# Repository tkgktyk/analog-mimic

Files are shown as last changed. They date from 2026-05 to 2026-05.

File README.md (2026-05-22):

# Analog Mimic (analog-mimic)

<!-- ![Analog Mimic Board](docs/images/analog_mimic_board.jpg) -->

## Overview
Analog Mimic is a drop-in, programmable analog front-end (AFE) module powered by a robust "MCU + DSP" architecture. It is designed to bring software-defined flexibility to physical analog boundaries.

**Key Features:**
* **Versatile Emulation:** Physically mimics diverse analog circuits (e.g., filters, amplifiers, comparators).
* **Instant Reconfiguration:** Fully reconfigurable on the fly with a single I²C command.
* **Drop-in Ready:** Designed to be easily integrated into your existing hardware prototyping workflow.

<!-- ## Underlying Technology
**Analog Mimic is powered by OtoHA.**

OtoHA (Optimization toward Hardware-deterministic Architecture) is the foundational framework established in our IEEE ESL paper: *"Sub-Clock Hardware-Deterministic Architecture for Phase-Accurate Analog Emulation on Resource-Constrained MCUs"*. 

By isolating the critical execution path and eliminating architectural timing penalties, OtoHA ensures strict time-invariance and hardware-like precision, allowing standard microcontrollers to operate as strictly deterministic mixed-signal blocks. -->

## Hardware Concept
* **Form Factor:** Pmod Type 6 (I²C) compatible layout with a compact, breadboard-friendly footprint (35.56 mm × 20 mm).
* **On-Chip Integration:** Seamless integration of internal operational amplifier-based input/output buffers, anti-aliasing filters (AAF), and anti-imaging filters (AIF) mapped directly alongside the high-speed processing core.

## Software Ecosystem
To lower the barrier to entry for real-time digital signal processing, we provide a dedicated **C++ library for Arduino**. 
* **Zero-Hassle Control:** Complex Q15 fixed-point arithmetic and low-level I²C register maps are completely abstracted away.
* **Intuitive High-Level API:** Users can dynamically switch emulation modes and fine-tune physical parameters—such as cutoff frequencies, amplifier gains, or envelope release times—by simply passing variables into straightforward function calls.

*For comprehensive details on the inner workings, execution framework, and API configurations, please refer to [firmware_reference.md](docs/firmware_reference.md) and the Doxygen-annotated [Mimic.h](software/Mimic/src/Mimic.h).*

## Product Lineup
* **mimic0x (Standard Type):** The base model optimized for standard analog emulation and generalized mixed-signal prototyping.
* **mimic1x (AFE Extended Type):** An enhanced version featuring expanded hardware-level analog front-end scaling for specialized sensor interfacing.

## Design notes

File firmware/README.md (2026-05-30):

# firmware/README.md

This directory contains the core firmware source code, peripheral drivers, and build configurations for the Analog Mimic module. This guide outlines the setup required for compiling the firmware from source and flashing the compiled binary onto the target microcontroller.

## 1. Development Environment Setup

Analog Mimic firmware is targeted for the Puya Semiconductor PY32F071 MCU (Arm Cortex-M0+, 72 MHz). To compile and flash the firmware, the following toolchains and utility tools are required.

### Required Software Components

1. **GCC ARM Embedded Toolchain (`arm-none-eabi-gcc`)**
* Used for compiling and linking the C/C++ source code into an ARM architecture binary.
* Ensure it is added to your system environment variable `PATH`.

2. **Build Automation Tool (`make` or `CMake`)**
* Standard GNU Make is utilized to execute the compilation pipeline via the `Makefile`.

3. **Python 3.x & pyOCD**
* pyOCD is an open-source Python library used for programming and debugging ARM Cortex microcontrollers via a CMSIS-DAP debugger.

---

## 2. Compilation and Build Pipeline

To compile the firmware, navigate to this directory and use the build configuration. The optimization flags are strictly configured (`-O2` or `-O3`) to meet the strict 240-clock-cycle budget for the 300 kHz primary ISR loop, and `.ramfunc` routes time-critical instructions into zero-wait-state SRAM.

### Build Commands

* **Compile Firmware:**
```bash
make release
```

*This generates the compiler outputs in the `build/` directory, resulting in `analog_mimic_MIMIC00.elf`, `.bin`, and `.hex` files.*
* **Clean Build Artifacts:**
```bash
make clean
```

---

## 3. Flashing & Debug Environment

Target programming is handled asynchronously via the SWD (Serial Wire Debug) pins using a standard CMSIS-DAP compliant debug probe.

### Target MCU Specification

* **Target Device:** Puya PY32F071xB
* **Memory Config:** 128 KB Flash / 16 KB SRAM

### Flash Programming via pyOCD

pyOCD natively supports the PY32 series by loading the corresponding device pack. Execute the following continuous command to flash the compiled production Intel HEX image onto the MCU:

```bash
pyocd flash -t py32f071xb analog_mimic_MIMIC00.hex

```

### Hardware Verification Setup

```
[ Host PC ]
    │ (USB)
    ▼
[ CMSIS-DAP Debugger ] (e.g., DAPLink, J-Link in DAP mode)
    │ (SWD Interface: SWCLK, SWDIO, GND, 3.3V)
    ▼
[ Analog Mimic Board ] (PY32F071 Target Pins)

```

1. Connect your CMSIS-DAP debugger to the SWD test points on the Analog Mimic PCB.
2. Power the module via the Pmod interface or the VDD pin (3.3V).
3. Run the `pyocd flash` command. Upon successful completion, reset the MCU to initiate the execution framework and launch the 300 kHz ADC sampling pipeline.

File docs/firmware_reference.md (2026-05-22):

# Firmware Reference

This document provides a technical overview of the Analog Mimic firmware. It details the OtoHA execution framework, hardware resource allocations, internal DSP mechanics, and the I²C control interface, serving as a guide for users who wish to understand the core software pipeline.

## 1. Internal MCU Processing

The firmware pipeline executes sequentially within the hardware-locked Primary ISR to maintain absolute temporal determinism.

```
[Analog In]
   ↓
(1) ADC Read (12-bit Raw)
   ↓
(2) Mode-Specific DSP Core (32-bit state execution)
   ↓
(3) Common Post-processing 1: Branchless DAC Code Inversion & DC Offset
   ↓
(4) Common Post-processing 2: Fixed-point Saturation (Clamps strictly to 0 - 4095)
   ↓
(5) DAC Preload (Next cycle output)
   ↓
[Analog Out]

```

---

## 2. Hardware Resource Mapping

Analog Mimic is built around the Puya Semiconductor PY32F071, a low-cost 72 MHz Arm Cortex-M0+ MCU. The continuous-time signal chain defined in the architecture is mapped directly to the MCU's internal peripherals.

### Peripheral Assignment Table

| Hardware Resource | Internal Peripheral | Firmware Function / Mapping |
| --- | --- | --- |
| **System Core Clock** | HSI Oscillator | Configured to 72 MHz via internal PLL. |
| **Sampling Clock** | TIM3 (16-bit Advanced Timer) | Configured in up-counting mode to generate periodic Update Interrupts at exactly 300 kHz (Priority 0: Primary ISR). |
| **Input Buffer** | OPA1 | Configured as a Hi-Z voltage follower. |
| **Anti-Aliasing Filter (AAF)** | OPA3 | Configured as a 2nd-order Sallen-Key Low-Pass Filter ($Q = 0.5$, $f_c = 48.2$ kHz). |
| **Analog Input Interface** | ADC1 (12-bit, Successive Approx.) | Mapped to internal channels or pins depending on the variant. Set to high-speed single-conversion mode triggered automatically by the timer. |
| **Primary Analog Output** | DAC1 (12-bit R-2R Ladder) | Wired directly to the output smoothing chain (AOUT). Driven by an immediate software trigger (SWTRIGR = 1) at the very first instruction of the Primary ISR, latching the pre-calculated code. |
| **Anti-Imaging Filter (AIF)** | OPA2 | Configured as a 2nd-order Sallen-Key Low-Pass Filter ($Q = 0.5$, $f_c = 48.2$ kHz). |
| **Host Communication** | I2C1 (Hardware Block) | Mapped to Scl/Sda lines for host-level runtime reconfiguration (Priority 1: Secondary ISR). |

---

<!-- ## 3. OtoHA Execution Framework

Analog Mimic achieves hardware-like temporal determinism on a resource-constrained microcontroller by implementing the OtoHA (Optimization toward Hardware-deterministic Architecture) framework. To balance strict phase-accuracy with topological reconfigurability, the firmware bifurcates execution into two distinct states.

### Hardware and Software Mapping

```
+---------------------------------------------------------------------------------+
|                                 MCU EXECUTION                                   |
+---------------------------------------------------------------------------------+
|  [Deterministic State]                         [Non-Deterministic State]        |
|                                                                                 |
|  Primary ISR                                   Secondary ISR      Main Loop     |
|  (Priority 0)                                  (Priority 1)       (Background)  |
|       │                                             │                  │        |
|       ▼                                             ▼                  ▼        |
|  Tied directly to:                             Tied to:           Tied to:      |
|  300 kHz Hardware Timer                        Asynchronous       Parameter     |
|  & Periodic ADC Sampling                       I2C Transactions   Decoding &    |
|                                                                   Q15 Scaling   |
+---------------------------------------------------------------------------------+

```

### Deterministic State (Mapped to Primary ISR & 300 kHz ADC Sampling)

* **Hardware Binding:** This state is implemented inside the Primary ISR, which is tied directly to a hardware timer interrupt set to a strict 300 kHz sampling rate (3.3 µs sample period). This timer commands the ADC to initiate conversions at absolute periodic intervals.
* **Execution Pipeline:** Executes the time-critical mixed-signal chain. Upon the 300 kHz hardware trigger, the CPU bypasses standard interrupt latencies to issue an immediate software trigger to the DAC (presenting the pre-calculated analog code from the previous sample). It then reads the newly converted 12-bit raw value from the ADC, routes it through the active 32-bit promoted DSP emulation core, and performs common post-processing (branchless inversion, offset, and clamping) to preload the DAC for the next cycle.
* **Zero-Jitter Optimizations:** To guarantee sub-clock execution determinism (<13 ns jitter) across the 300 kHz ADC boundary, the NVIC vector table and the entire Primary ISR instruction routine are moved to zero-wait-state SRAM via the `.ramfunc` attribute. Active emulation explicitly suspends asynchronous system background tasks (such as the standard SysTick handler) to prevent nested preemption.

### Non-Deterministic State (Mapped to I²C Interrupts & Main Loop)

* **Hardware Binding:** This state handles external host communication and is bifurcated into the I²C peripheral interrupt (Secondary ISR) and the background Main Loop.
* **Execution Pipeline:** Manages topological and parameter updates. When a host microcontroller (e.g., an Arduino) issues a configuration command, the hardware I²C interrupt (Secondary ISR) triggers at a lower priority (Priority 1) to capture incoming payload bytes into a temporary data buffer without interrupting the active Primary ISR. Once the transfer completes, the background Main Loop takes over to decode the commands, translate human-readable physical parameters (such as cutoff frequencies in Hz or decay times in microseconds) into digital raw values or Q15 fixed-point coefficients, and safely hot-swaps the DSP routing mode.

### Cycle Budget Allocation

Operating a 72 MHz Cortex-M0+ core at a 300 kHz sampling rate compresses the total single-sample computational window into a strict budget of 240 clock cycles per sample.

```
5 µs Sample Period @ 72 MHz Core Clock
|←───────────────────────── 240 Clock Cycles ─────────────────────────→|
┌───────────────────────────────────────────────┬──────────────────────┐
│ Core DSP Execution                            │ Required Slack       │
│ (e.g., Fixed-Point Emulation Routine)         │ (60 - 70 Cycles)     │
└───────────────────────────────────────────────┴──────────────────────┘
                                                ▲
                                                └── Mapped to:
                                                    - I2C ISR Overhead
                                                    - Main Loop Decoding

```

* **DSP Execution:** Highly optimized fixed-point routines execute inside the Primary ISR, consuming a predictable chunk of the sample budget.
* **Slack Margin:** The framework rigorously maintains a required slack margin of 60 to 70 clock cycles outside of the core DSP execution. This deterministic cycle reserve is dedicated entirely to non-DSP operations—specifically handling the I²C Secondary ISR communication overhead and allowing the background Main Loop to calculate new filter coefficients before the next WFI (Wait-For-Interrupt) synchronization boundary.

--- -->

## 4. DSP Core & Fixed-Point Arithmetic

To maximize efficiency within the 240-cycle budget, the firmware completely avoids runtime floating-point arithmetic. All mathematical emulation blocks are implemented using a 32-bit promoted Q15 fixed-point representation.

### Fixed-Point Format & 32-bit Promotion

In the Q15 format, a signed integer represents a fractional value in the range $[-1.0, 1.0 - 2^{-15}]$:

$$\text{Value}_{\text{Float}} = \frac{\text{Internal integer}}{32768}$$

To eliminate memory alignment padding gaps and avoid redundant CPU cast instructions on the 32-bit Cortex-M0+ architecture, all internal DSP states and arithmetic operations are natively promoted to `int32_t` (`FRACTIONAL_BITS_Q15 = 15`).

* **Addition / Subtraction:** Executed natively using 32-bit registers.
* **Multiplication:** Performed using native 32-bit arithmetic. The 32-bit intermediate product is immediately shifted right by 15 bits (`>> 15`) to maintain the Q15 fractional scale, without dropping back to 16 bits until the final DAC bounds clamping.

### Parameter Processing & Scaling

When a host passes a physical parameter (such as a cutoff frequency in Hz or an integration time constant in microseconds) over I²C, the firmware does not use these values directly inside the Primary ISR. Instead, the Secondary ISR intercepts the parameters and converts them into normalized digital coefficients (such as $b_0, b_1, a_1$ coefficients or pre-calculated decay multipliers) using a background fixed-point conversion library.

* **Voltage Inputs (mV to Raw 12-bit ADC/DAC Codes):**
* Unsigned:

$$\text{Raw} = \frac{\text{mV} \times 4095}{V_{DD\_mV}}$$

* Signed (Centered around $V_{DD}/2$ mid-rail):

$$\text{Raw}_{\text{Signed}} = \frac{\text{mV} \times 2048}{V_{DD\_mV}/2}$$

* **Frequency Inputs ($f_c$ in Hz to Biquad Coeffs):**
Pre-warped digital angular frequencies $\omega_0 = 2\pi f_c / f_s$ are mapped to Q15 filter coefficients using optimized Taylor-series polynomial approximations for sine and cosine.

### Parameter Specification & Payload Types Table

When the host configures a DSP mode, it sends parameters over I²C using specific data types. The following table defines these payload types, classifying how human-readable physical units are translated into the raw bytes utilized by the DSP core.

| Payload Type | Logical Parameter | User/Host Unit | Hardware / Internal Mapping |
| --- | --- | --- | --- |
| **S16** *(Signed 16-bit)* | Q15 Coefficient (Freq $f_c$, Time Const $\tau$, Gain) | Hz, $\mu$s, or Float | Converted by the host into Q15 fractional format $[-1.0, 1.0)$. Used internally for digital filters ($b_n, a_n$), integration/decay factors, and fractional scaling. |
| **S16 / U16** *(16-bit Integer)* | Raw ADC Code / Offset (Threshold, $V_{\text{ref}}$, DC Offset) | mV | Transformed by the host from physical voltage to a 12-bit raw integer $[0 - 4095]$. U16 is typically used for absolute thresholds, while S16 is used for offsets and clipping limits. |
| **S8** *(Signed 8-bit)* | Bit-Shift Multiplier (Coarse Gain) | Integer | Used in conjunction with Q15 fractional multipliers. Performs fast coarse scaling via bit-shifting (e.g., $\ll 2$ for $4\times$ gain, or $\gg 1$ for attenuation). |
| **U16** *(Unsigned 16-bit)* | Sample Count (Delay time, S&H period) | Samples (Integer) | Represents an exact number of 300 kHz clock cycles. Used directly for delay buffer sizing and downsampling counters. |
| **U8** *(Unsigned 8-bit)* | Flag / Enumeration (Polarity, LUT Type) | Boolean / Enum | Simple 1-byte selection codes. Maps to conditional branching flags (e.g., peak vs. trough) or Look-Up Table target pointers. |

---

## 5. I²C Interface & Mode Specifications

The internal topology of the Analog Mimic is fully reconfigurable at runtime via an 8-bit memory-mapped I²C register interface.

### Register Map Overview

The device utilizes a fixed memory map bridging host interactions and the internal DSP state machine. Registers 0x00 through 0x1F reside in physical SRAM (`mimic_device.registers`), whereas telemetry addresses (0x20+) are virtual and dynamically latched upon host read requests to guarantee thread safety.

| Address | Register Name | Access | Width | Description |
| --- | --- | --- | --- | --- |
| **0x00** | MIMIC_REG_GLOBAL_FLAGS | R/W | 8-bit | System overrides. Bit 7 (0x80): Output Invert, Bit 6 (0x40): Output Open (Hi-Z), Bit 5 (0x20): Servo Enable. |
| **0x01** | MIMIC_REG_OUTPUT_OFFSET_H | R/W | 8-bit | MSB of global DC offset applied universally post-DSP. |
| **0x02** | MIMIC_REG_OUTPUT_OFFSET_L | R/W | 8-bit | LSB of global DC offset. |
| **0x10** | MIMIC_REG_MODE_SELECT | R/W | 8-bit | Selects the active DSP routing topology (Mode ID). |
| **0x11+** | MIMIC_REG_PAYLOAD_START | R/W | Block | Mode-specific parameter buffer. Interpreted based on MODE_SELECT. |
| **0x20** | MIMIC_REG_STATUS | R/C | 8-bit | System Status Flags (Bit 0: Ready, Bit 1: Saturation, Bit 2: I2C Error, Bit 3: ADC Over Error). Cleared on read. |
| **0x21** | MIMIC_REG_ADC_VAL_H | R | 8-bit | MSB of the live 12-bit ADC tracking conversion. |
| **0x22** | MIMIC_REG_ADC_VAL_L | R | 8-bit | LSB of the live 12-bit ADC conversion. |
| **0x23** | MIMIC_REG_CPU_CYCLES_H | R/C | 8-bit | MSB of peak execution cycles per sample. Cleared on read. |
| **0x24** | MIMIC_REG_CPU_CYCLES_L | R/C | 8-bit | LSB of peak execution cycles per sample. |

### Operational Mode Specifications

The host triggers a pipeline reconfiguration by writing the target Mode ID to `MIMIC_REG_MODE_SELECT` (0x10), followed by mode-specific bytes starting at `MIMIC_REG_PAYLOAD_START` (0x11).

#### 0x00: DSP Bypass (`MIMIC_MODE_ID_BYPASS_DSP`)

* **Function:** Acts as a strictly deterministic voltage follower.
* **Implementation:** The ADC input is routed directly to the DAC. Global pipeline effects (Inversion, Offset) remain active.
* **Payload Parameters:** None.

#### 0x01: Programmable Gain Amplifier (`MIMIC_MODE_ID_PGA`)

* **Function:** Scales the input signal linearly with respect to an arbitrary reference center.
* **Implementation:** Combines a Q15 fractional multiplier for fine-tuning and a bit-shift operation for gross hardware-like amplification.
* **Payload Parameters:** * 0x11-0x12 (S16): `gain_fract_q15` - Fractional gain multiplier.
* 0x13 (S8): `gain_shift` - Coarse bit-shift multiplier.
* 0x14-0x15 (S16): `offset_raw` - DC offset reference center (Raw ADC code). Internally mapped to Q15.

#### 0x02: 1st-Order Low-Pass Filter (`MIMIC_MODE_ID_FILTER_1ST_LPF`)

* **Function:** Emulates a continuous-time RC low-pass filter.
* **Implementation:** Standard infinite impulse response (IIR) single-pole accumulator.
* **Payload Parameters:**
* 0x11-0x12 (S16): `alpha_q15` - Decay/Integration coefficient derived from target $f_c$.

#### 0x03: 1st-Order High-Pass Filter (`MIMIC_MODE_ID_FILTER_1ST_HPF`)

* **Function:** Emulates an RC high-pass network (useful for automatic DC-blocking/servo tracking).
* **Implementation:** Single-pole accumulator with the state subtracted from the raw input.
* **Payload Parameters:**
* 0x11-0x12 (S16): `alpha_q15` - Cutoff frequency coefficient.

#### 0x04: 2nd-Order Biquad Filter (`MIMIC_MODE_ID_FILTER_BIQUAD`)

* **Function:** Universal 2nd-order digital filter configurable as LPF, HPF, BPF, or Notch.
* **Implementation:** Direct Form II Transposed (DF2T). Highly unrolled loop loading coefficients aggressively into CPU registers. Dominates the processing budget (~212 cycles).
* **Payload Parameters:**
* 0x11-0x12 (S16): `b0` - Feedforward coefficient 0.
* 0x13-0x14 (S16): `b1` - Feedforward coefficient 1.
* 0x15-0x16 (S16): `b2` - Feedforward coefficient 2.
* 0x17-0x18 (S16): `a1` - Feedback coefficient 1.
* 0x19-0x1A (S16): `a2` - Feedback coefficient 2.

#### 0x05: Window Comparator (`MIMIC_MODE_ID_COMPARATOR_WIN`)

* **Function:** Triggers output HIGH when the signal escapes the defined upper/lower boundaries.
* **Implementation:** Pure conditional branching logic outputting absolute 12-bit limits.
* **Payload Parameters:**
* 0x11-0x12 (U16): `upper` - Raw ADC threshold code (Upper bound).
* 0x13-0x14 (U16): `lower` - Raw ADC threshold code (Lower bound).

#### 0x06: Schmitt Trigger (`MIMIC_MODE_ID_COMPARATOR_SCHMITT`)

* **Function:** A comparator with hysteresis memory, preventing noisy transitions.
* **Implementation:** Conditional branching retaining state memory (`wave_last_raw`).
* **Payload Parameters:**
* 0x11-0x12 (U16): `upper` - Trigger HIGH threshold.
* 0x13-0x14 (U16): `lower` - Trigger LOW threshold.

#### 0x07: Envelope Follower (`MIMIC_MODE_ID_ENVELOPE_FOLLOWER`)

* **Function:** Tracks amplitude peaks (or troughs) with a customizable decay release time. Acts as a Peak Hold if decay is zero.
* **Implementation:** Multiplies the historical state by a Q15 decay factor when the input falls below the tracked envelope.
* **Payload Parameters:**
* 0x11-0x12 (S16): `decay_q15` - Q15 decay factor (derived from $\tau$ us).
* 0x13 (U8): `polarity` - Positive peak (0) or Negative trough (1) tracking.

#### 0x08: Signal Clipper (`MIMIC_MODE_ID_CLIPPER`)

* **Function:** Clamps the output signal strictly within absolute physical voltage boundaries.
* **Implementation:** Standard boundary threshold branching limits.
* **Payload Parameters:**
* 0x11-0x12 (S16): `upper` - Upper clamp limit (Raw).
* 0x13-0x14 (S16): `lower` - Lower clamp limit (Raw).

#### 0x09: Non-linear LUT Waveshaper (`MIMIC_MODE_ID_NONLINEAR_LUT`)

* **Function:** Emulates analog logarithmic and anti-logarithmic amplification curves.
* **Implementation:** Instead of heavy runtime Taylor series execution, maps a pre-computed 65-point Look-Up Table (LUT) across the ADC range, utilizing single-cycle linear interpolation for sub-index accuracy.
* **Payload Parameters:**
* 0x11 (U8): `lut_type` - 0 for Logarithmic, 1 for Anti-Logarithmic.

#### 0x0A: Signal Derivative (`MIMIC_MODE_ID_MATH_DERIVATIVE`)

* **Function:** Mathematical differentiator (extracts the rate of change).
* **Implementation:** Calculates $\Delta$ between the current and previous sample, scaled by a fractional Q15 multiplier and bit-shift.
* **Payload Parameters:**
* 0x11-0x12 (S16): `scale_fract_q15` - Base scaling multiplier.
* 0x13 (S8): `scale_shift` - Coarse gain shift multiplier.

#### 0x0B: Leaky Integral (`MIMIC_MODE_ID_MATH_INTEGRAL`)

* **Function:** Accumulates the input signal over time.
* **Implementation:** Standard accumulator that slightly attenuates (leaks) the historical state using a fractional multiplier to prevent unbounded signal saturation.
* **Payload Parameters:**
* 0x11-0x12 (S16): `scale_fract_q15` - Leaky attenuation factor for historical state.
* 0x13 (S8): `scale_shift` - Dynamic gain scale for new incoming samples.

#### 0x0C: Full-Wave Rectifier (`MIMIC_MODE_ID_RECTIFIER_FULL`)

* **Function:** Absolute value mathematical operation (folds negative half-cycles up).
* **Implementation:** Branches around a defined center reference voltage (`vref_raw`).
* **Payload Parameters:**
* 0x11-0x12 (S16): `vref_raw` - Symmetrical center voltage reference code.

#### 0x0D: Slew Rate Limiter (`MIMIC_MODE_ID_SLEW_RATE_LIMITER`)

* **Function:** Limits how fast the voltage can physically change per sample ($\Delta V / \Delta t$).
* **Implementation:** Calculates the delta and clamps it mathematically without heavy pipeline-flushing jumps (branchless clamp logic).
* **Payload Parameters:**
* 0x11-0x12 (S16): `scale_fract_q15` - Maximum allowed delta per 300 kHz sample.

#### 0x0E: Sample & Hold (`MIMIC_MODE_ID_SAMPLE_AND_HOLD`)

* **Function:** Freezes the analog signal at a specified interval (downsampling).
* **Implementation:** Utilizes an internal sample counter to hold `last_q15` constant until the tracking threshold is breached.
* **Payload Parameters:**
* 0x11-0x12 (U16): `period_samples` - Total duration of the T&H cycle.
* 0x13-0x14 (U16): `track_samples` - Duration spent tracking before holding.

#### 0x0F: Digital Delay (`MIMIC_MODE_ID_DELAY`)

* **Function:** Pure time-delay buffer without filtering.
* **Implementation:** Allocates a contiguous ring buffer (`delay_buffer[4096]`) masking the write pointer mathematically for safe wraparound.
* **Payload Parameters:**
* 0x11-0x12 (U16): `delay_samples` - Number of samples to hold in memory.

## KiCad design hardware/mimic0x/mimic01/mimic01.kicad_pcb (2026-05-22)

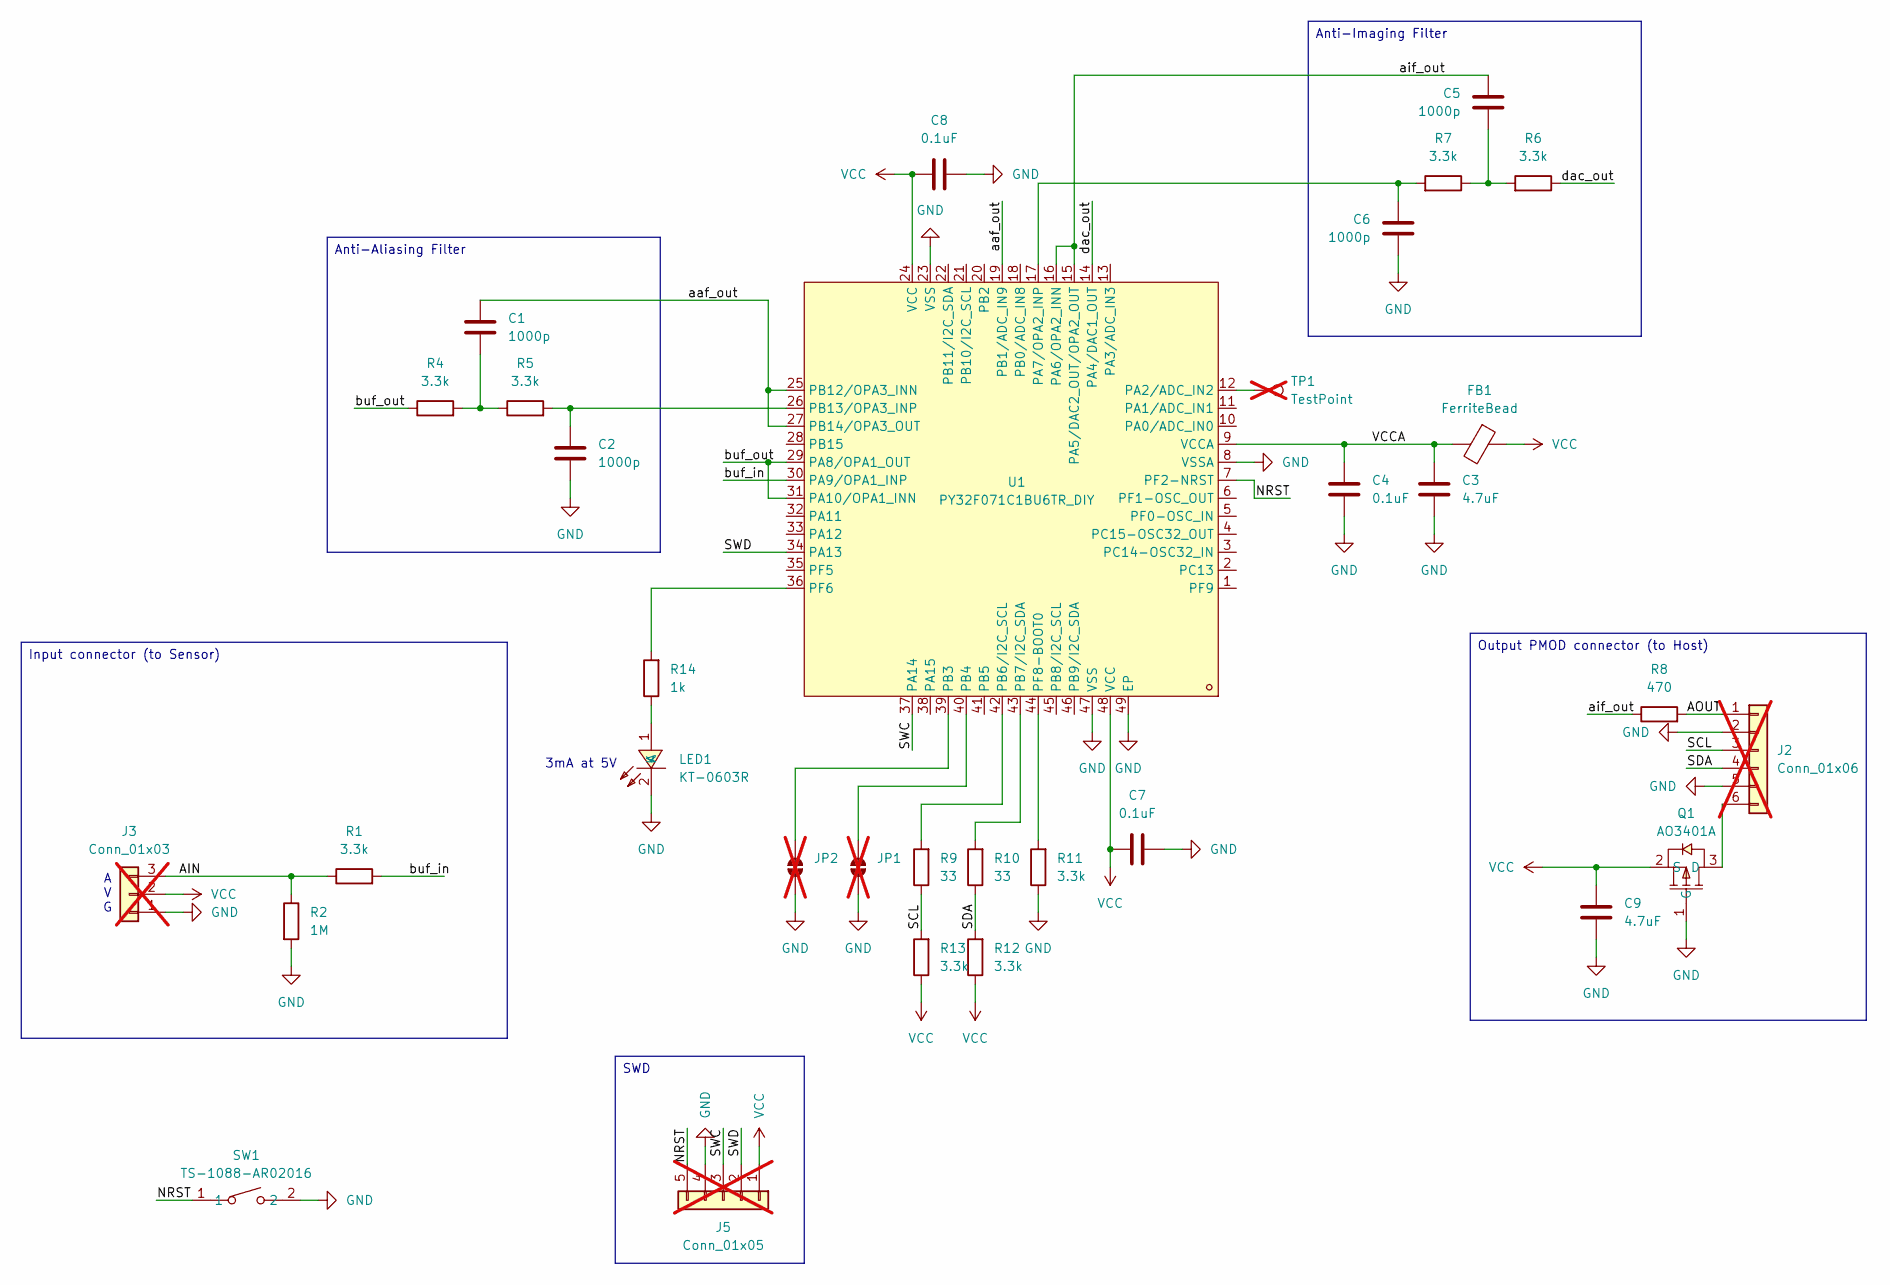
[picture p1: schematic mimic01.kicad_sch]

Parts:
C1, C2, C5, C6: 1000p; C_0402_1005Metric; LCSC Part C53547
C3, C9: 4.7uF; C_0603_1608Metric; LCSC Part C19666
C4, C7, C8: 0.1uF; C_0402_1005Metric; LCSC Part C1525
FB1: FerriteBead; L_0603_1608Metric; LCSC Part C1002
J2: Conn_01x06; PinHeader_1x06_P2.54mm_Horizontal_DIY; not fitted
J3: Conn_01x03; PinHeader_1x03_P2.54mm_Horizontal_DIY; not fitted
J5: Conn_01x05; PinSocket_1x05_P2.54mm_Vertical_DIY; not fitted
JP1, JP2: SolderJumper_2_Open; SolderJumper-2_P1.3mm_Open_TrianglePad1.0x1.5mm; not fitted
LED1: KT-0603R; LED-SMD_L1.6-W0.8-R-RD; MPN KT-0603R; LCSC Part C2286
Q1: AO3401A; SOT-23_L2.9-W1.3-P1.90-LS2.4-BR; MPN AO3401A; LCSC Part C15127
R1, R4, R5, R6, R11, R12, R13: 3.3k; R_0402_1005Metric; LCSC Part C25890
R2: 1M; R_0402_1005Metric; LCSC Part C26083
R7: 3.3k; R_0603_1608Metric; LCSC Part C22978
R8: 470; R_0402_1005Metric; LCSC Part C25117
R9, R10: 33; R_0402_1005Metric; LCSC Part C25105
R14: 1k; R_0402_1005Metric; LCSC Part C11702
SW1: TS-1088-AR02016; SW-SMD_L3.9-W3.0-P4.45; MPN TS-1088-AR02016; LCSC Part C720477
TP1: TestPoint; TestPoint_Pad_D1.5mm; not fitted
U1: PY32F071C1BU6TR_DIY; VQFN-48_L6.0-W6.0-P0.40-TL-EP4.4; LCSC Part C7434410

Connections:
/AIN: J3.3, R1.1, R2.1
/AOUT: J2.1, R8.2
/NRST: J5.5, SW1.1, U1.7 (PF2-NRST)
/SCL: J2.3, R9.1, R13.2
/SDA: J2.4, R10.1, R12.2
/SWC: J5.3, U1.37 (PA14)
/SWD: J5.2, U1.34 (PA13)
/VCCA: C3.1, C4.1, FB1.2, U1.9 (VCCA)
/aaf_out: C1.1, U1.19 (PB1/ADC_IN9), U1.25 (PB12/OPA3_INN), U1.27 (PB14/OPA3_OUT)
/aif_out: C5.1, R8.1, U1.15 (PA5/DAC2_OUT/OPA2_OUT), U1.16 (PA6/OPA2_INN)
/buf_in: R1.2, U1.30 (PA9/OPA1_INP)
/buf_out: R4.1, U1.29 (PA8/OPA1_OUT), U1.31 (PA10/OPA1_INN)
/dac_out: R6.1, U1.14 (PA4/DAC1_OUT)
GND: C2.2, C3.2, C4.2, C6.2, C7.2, C8.2, C9.2, J2.2, J2.5, J3.1, J5.4, JP1.1 (A), JP2.1 (A), LED1.2 (K), Q1.1 (G), R2.2, R11.1, SW1.2, U1.8 (VSSA), U1.23 (VSS), U1.47 (VSS), U1.49 (EP)
unnamed: C1.2, R4.2, R5.1
unnamed: C5.2, R6.2, R7.1
unnamed: J2.6, Q1.3 (D)
unnamed: JP1.2 (B), U1.40 (PB4)
unnamed: JP2.2 (B), U1.39 (PB3)
unnamed: LED1.1 (A), R14.1
unnamed: TP1.1, U1.12 (PA2/ADC_IN2)
unnamed: C6.1, R7.2, U1.17 (PA7/OPA2_INP)
unnamed: R9.2, U1.42 (PB6/I2C_SCL)
unnamed: R10.2, U1.43 (PB7/I2C_SDA)
unnamed: C2.1, R5.2, U1.26 (PB13/OPA3_INP)
unnamed: R14.2, U1.36 (PF6)
unnamed: R11.2, U1.44 (PF8-BOOT0)
VCC: C7.1, C8.1, C9.1, FB1.1, J3.2, J5.1, Q1.2 (S), R12.1, R13.1, U1.24 (VCC), U1.48 (VCC)

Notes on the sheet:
3mA at 5V
A V G
Input connector (to Sensor)
SWD
Output PMOD connector (to Host)
Anti-Imaging Filter
Anti-Aliasing Filter

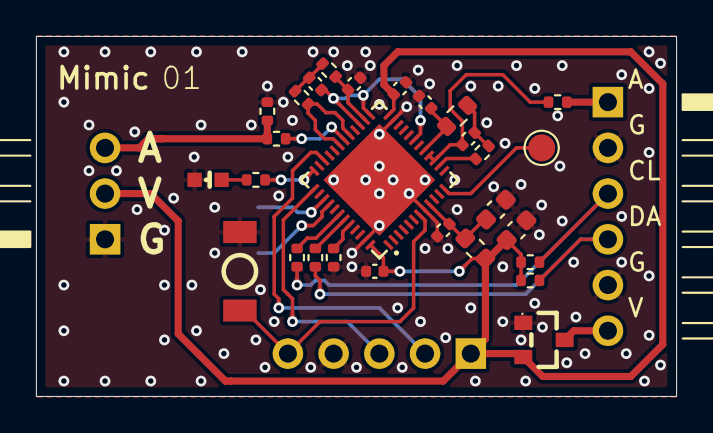
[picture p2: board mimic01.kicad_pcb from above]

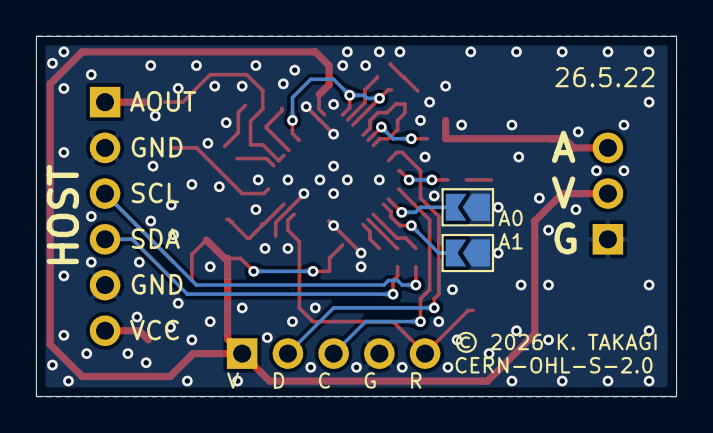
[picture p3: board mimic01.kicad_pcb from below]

Board: 2 copper layers, 35.6 x 20.0 mm, 33 parts (2 on the bottom side), 28 nets.

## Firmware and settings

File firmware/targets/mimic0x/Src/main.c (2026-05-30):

/**
 ******************************************************************************
 * @file    main.c
 * @author  TAKAGI Katsuyuki
 * @brief   Main Application Entry Point, Core System Lifecycle Management, 
 * and Background Non-Deterministic Parameter Processing Loop.
 *-----------------------------------------------------------------------------
 * Copyright (C) 2026 TAKAGI Katsuyuki
 *
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
 * You should have received a copy of the GNU General Public License
 * along with this program.  If not, see <https://www.gnu.org/licenses/>.
 ******************************************************************************
 */

#include "py32f0xx_hal.h"
#include "py32f071_ll_i2c.h"

#include "mimic0x_msp.h"
#include "mimic_registers.h"
#include "mimic_device.h"

// =========================================================
// Configuration Macros
// =========================================================

#define VECTOR_TABLE_SIZE 48

// Peripheral configuration constants
#define I2C_CLOCK_SPEED_HZ 100000
#define I2C_SLAVE_ADDRESS (MIMIC_DEFAULT_I2C_ADDR << 1) // 7-bit address "0x40"

// CRITICAL TIMING CONSTRAINT:
// To prevent starvation of the I2C peripheral and the main loop,
// the system requires a strict margin of approximately 60-70 CPU cycles per sample.
// Maximum allowable DSP execution cycles = (SYSTEM_CLOCK_HZ / TARGET_SAMPLING_HZ) - 65.
// Exceeding this budget will result in I2C timeouts and system lockups.
#define TIM3_SAMPLING_PERIOD ((MIMIC_SYSTEM_CLOCK_HZ / MIMIC_ADC_SAMPLING_HZ) - 1)
_Static_assert((MIMIC_SYSTEM_CLOCK_HZ % MIMIC_ADC_SAMPLING_HZ) == 0, 
               "Configuration Error: MIMIC_SYSTEM_CLOCK_HZ must be perfectly divisible by MIMIC_ADC_SAMPLING_HZ to prevent jitter.");

// =========================================================
// Global Variables
// =========================================================

__attribute__((aligned(256))) uint32_t ram_vector_table[VECTOR_TABLE_SIZE];

// HAL Peripheral Handles
ADC_HandleTypeDef hadc1;
DAC_HandleTypeDef hdac1;
TIM_HandleTypeDef htim3;
OPA_HandleTypeDef hopa1;
OPA_HandleTypeDef hopa2;
OPA_HandleTypeDef hopa3;

// =========================================================
// Initialization Function Prototypes
// =========================================================
static void RelocateVectorTableToRAM(void);
static void APP_ErrorHandler(void);
static void SystemClock_Config(void);
static void MX_GPIO_Init(void);
static void MX_I2C1_Init(void);
static void MX_ADC1_Init(void);
static void MX_DAC_Init(void);
static void MX_TIM3_Init(void);
static void MX_OPA_Init(void);

// =========================================================
// Hardware Callback Implementations
// =========================================================

// Implements specific hardware control requested by the core for "OPEN state"
void MimicCallback_DisableOutput(void) {
    HAL_OPA_Stop(&hopa2);
}

void MimicCallback_EnableOutput(void) {
    HAL_OPA_Start(&hopa2); 
}

// =========================================================
// Main Routine
// =========================================================
int main(void) {
  HAL_Init();
  SystemClock_Config();

  // 1. Initialize Peripherals
  MX_GPIO_Init();
  MX_I2C1_Init();
  MX_ADC1_Init();
  MX_DAC_Init();
  MX_OPA_Init();
  MX_TIM3_Init();

  // 2. Initialize Analog Mimic Core Logic
  MimicDevice_Init(&MimicCallback_EnableOutput, &MimicCallback_DisableOutput);

  // 3. Relocate vector table to RAM for faster/safe ISR execution
  RelocateVectorTableToRAM();

  // 4. Start Peripherals
  HAL_ADC_Start_IT(&hadc1);
  HAL_DAC_Start(&hdac1, DAC_CHANNEL_1);
  HAL_TIM_Base_Start(&htim3);
  
  // 5. Halt SysTick as it is no longer required and saves cycles
  HAL_SuspendTick();

  // Initialization completed
  MimicDevice_SetStatusFlag(MIMIC_STATUS_SYSTEM_READY);
  Mimic_SetReadyLED(true);

  // Main background loop
  while (1) {
    MimicDevice_ProcessPendingTasks();

    // Execute WFI (Wait For Interrupt).
    // When a sampling interrupt (TIM3) occurs, execution jumps to the ISR 
    // via the VTOR relocated on SRAM.
    __asm volatile (
      "dsb \n" // Data Synchronization Barrier: Ensures data access completion
      "isb \n" // Instruction Synchronization Barrier: Flushes the pipeline
      "wfi \n" 
    );
  }
}

static void RelocateVectorTableToRAM(void) {
    // 1. Copy the vector table from Flash to RAM.
    uint32_t *flash_vectors = (uint32_t *)FLASH_BASE;
    
    for (int i = 0; i < VECTOR_TABLE_SIZE; i++) {
        ram_vector_table[i] = flash_vectors[i];
    }

    // 2. Data Synchronization Barrier (ensures write completion)
    __DSB();

    // 3. Update the VTOR register in the System Control Block (SCB)
    SCB->VTOR = (uint32_t)ram_vector_table;

    // 4. Instruction Synchronization Barrier (reflects settings immediately)
    __ISB();
}

// =========================================================
// Peripheral Initialization Implementations
// =========================================================
static void SystemClock_Config(void) {
  RCC_OscInitTypeDef RCC_OscInitStruct = {0};
  RCC_ClkInitTypeDef RCC_ClkInitStruct = {0};

  // 1. Configure HSI to 24MHz, enable PLL and multiply by 3 to achieve 72MHz
  RCC_OscInitStruct.OscillatorType = RCC_OSCILLATORTYPE_HSE | RCC_OSCILLATORTYPE_HSI | RCC_OSCILLATORTYPE_LSI | RCC_OSCILLATORTYPE_LSE;
  RCC_OscInitStruct.HSIState = RCC_HSI_ON;
  RCC_OscInitStruct.HSIDiv = RCC_HSI_DIV1;
  RCC_OscInitStruct.HSICalibrationValue = RCC_HSICALIBRATION_24MHz; 
  
  RCC_OscInitStruct.HSEState = RCC_HSE_OFF;
  RCC_OscInitStruct.LSIState = RCC_LSI_OFF;
  RCC_OscInitStruct.LSEState = RCC_LSE_OFF;

  // PLL Configuration
  RCC_OscInitStruct.PLL.PLLState = RCC_PLL_ON;
  RCC_OscInitStruct.PLL.PLLSource = RCC_PLLSOURCE_HSI;
  RCC_OscInitStruct.PLL.PLLMUL = RCC_PLL_MUL3; // HSI(24MHz) * 3 = 72MHz

  if (HAL_RCC_OscConfig(&RCC_OscInitStruct) != HAL_OK) {
    APP_ErrorHandler();
  }

  // 2. Clock distribution for each bus and FLASH latency configuration
  RCC_ClkInitStruct.ClockType = RCC_CLOCKTYPE_HCLK | RCC_CLOCKTYPE_SYSCLK | RCC_CLOCKTYPE_PCLK1;
  RCC_ClkInitStruct.SYSCLKSource = RCC_SYSCLKSOURCE_PLLCLK;
  RCC_ClkInitStruct.AHBCLKDivider = RCC_SYSCLK_DIV1;
  RCC_ClkInitStruct.APB1CLKDivider = RCC_HCLK_DIV1;

  // FLASH_LATENCY_2 is required for 72MHz operation
  if (HAL_RCC_ClockConfig(&RCC_ClkInitStruct, FLASH_LATENCY_2) != HAL_OK) {
    APP_ErrorHandler();
  }
  
  // Update the global variable with the newly configured core clock frequency
  SystemCoreClockUpdate();
}

static void MX_I2C1_Init(void) {
  // 1. Initialize hardware resources (Pins, Clocks, NVIC)
  Mimic_I2C1_Hardware_Init();

  // 2. I2C LL initialization (Logical parameters)
  LL_I2C_InitTypeDef I2C_InitStruct = {0};
  I2C_InitStruct.PeripheralMode  = LL_I2C_MODE_I2C;
  I2C_InitStruct.ClockSpeed      = I2C_CLOCK_SPEED_HZ;
  I2C_InitStruct.DutyCycle       = LL_I2C_DUTYCYCLE_2;
  I2C_InitStruct.OwnAddress1     = I2C_SLAVE_ADDRESS;
  I2C_InitStruct.TypeAcknowledge = LL_I2C_ACK;
  I2C_InitStruct.OwnAddrSize     = LL_I2C_OWNADDRESS1_7BIT;
  LL_I2C_Init(I2C1, &I2C_InitStruct);

  // Enable clock stretching and the peripheral itself
  LL_I2C_EnableClockStretching(I2C1);
  LL_I2C_Enable(I2C1);

  // Enable interrupts for slave operation
  LL_I2C_EnableIT_EVT(I2C1);
  LL_I2C_EnableIT_BUF(I2C1);
  LL_I2C_EnableIT_ERR(I2C1);
}

static void MX_ADC1_Init(void) {  
  ADC_ChannelConfTypeDef sConfig = {0};

  hadc1.Instance = ADC1;
  hadc1.Init.Resolution = ADC_RESOLUTION_12B;
  hadc1.Init.DataAlign = ADC_DATAALIGN_RIGHT;
  hadc1.Init.ScanConvMode = ADC_SCAN_DISABLE;
  hadc1.Init.ContinuousConvMode = DISABLE;
  hadc1.Init.NbrOfConversion = 1;
  hadc1.Init.DiscontinuousConvMode = DISABLE;
  hadc1.Init.NbrOfDiscConversion = 1;
  hadc1.Init.ExternalTrigConv = ADC_EXTERNALTRIGCONV_T3_TRGO;

  if (HAL_ADC_Init(&hadc1) != HAL_OK) {
    APP_ErrorHandler();
  }

  // Utilize the 5V power supply via VCCA
  if (HAL_ADC_ConfigVrefBuf(&hadc1, ADC_VREFBUF_VCCA) != HAL_OK) {
    APP_ErrorHandler();
  }
  
  // ADC Channel configuration (OPA3 Out -> PB1)
  sConfig.Channel = ADC_CHANNEL_9;
  sConfig.Rank = ADC_REGULAR_RANK_1;
  sConfig.SamplingTime = ADC_SAMPLETIME_13CYCLES_5;

  if (HAL_ADC_ConfigChannel(&hadc1, &sConfig) != HAL_OK) {
    APP_ErrorHandler();
  }

  // ADC calibration
  if (HAL_ADCEx_Calibration_Start(&hadc1) != HAL_OK) {
    APP_ErrorHandler();
  }
}

static void MX_DAC_Init(void) {
  DAC_ChannelConfTypeDef sConfig = {0};

  hdac1.Instance = DAC1;
  if (HAL_DAC_Init(&hdac1) != HAL_OK) {
    APP_ErrorHandler();
  }

  sConfig.DAC_Trigger = DAC_TRIGGER_SOFTWARE;
  sConfig.DAC_OutputBuffer = DAC_OUTPUTBUFFER_ENABLE;

  if (HAL_DAC_ConfigChannel(&hdac1, &sConfig, DAC_CHANNEL_1) != HAL_OK) {
    APP_ErrorHandler();
  }
}

static void MX_OPA_Init(void) {
  // OPA1 (Voltage Follower)
  hopa1.Instance = OPA;
  hopa1.Init.Part = OPA1;
  if (HAL_OPA_Init(&hopa1) != HAL_OK) {
    APP_ErrorHandler();
  }
  HAL_OPA_Start(&hopa1);

  // OPA2
  hopa2.Instance = OPA;
  hopa2.Init.Part = OPA2;
  if (HAL_OPA_Init(&hopa2) != HAL_OK) {
    APP_ErrorHandler();
  }
  HAL_OPA_Start(&hopa2);

  // OPA3
  hopa3.Instance = OPA;
  hopa3.Init.Part = OPA3;
  if (HAL_OPA_Init(&hopa3) != HAL_OK) {
    APP_ErrorHandler();
  }
  HAL_OPA_Start(&hopa3);
}

static void MX_TIM3_Init(void) {
  TIM_ClockConfigTypeDef sClockSourceConfig = {0};
  TIM_MasterConfigTypeDef sMasterConfig = {0};

  htim3.Instance = TIM3;
  htim3.Init.Prescaler = 0;
  htim3.Init.CounterMode = TIM_COUNTERMODE_UP;
  htim3.Init.Period = TIM3_SAMPLING_PERIOD;
  htim3.Init.ClockDivision = TIM_CLOCKDIVISION_DIV1;
  htim3.Init.RepetitionCounter = 0;
  htim3.Init.AutoReloadPreload = TIM_AUTORELOAD_PRELOAD_ENABLE;

  if (HAL_TIM_Base_Init(&htim3) != HAL_OK) {
    APP_ErrorHandler();
  }

  sClockSourceConfig.ClockSource = TIM_CLOCKSOURCE_INTERNAL;
  if (HAL_TIM_ConfigClockSource(&htim3, &sClockSourceConfig) != HAL_OK) {
    APP_ErrorHandler();
  }

  // Trigger ADC on Update event
  sMasterConfig.MasterOutputTrigger = TIM_TRGO_UPDATE;
  sMasterConfig.MasterSlaveMode = TIM_MASTERSLAVEMODE_DISABLE;
  if (HAL_TIMEx_MasterConfigSynchronization(&htim3, &sMasterConfig) != HAL_OK) {
    APP_ErrorHandler();
  }
}

static void MX_GPIO_Init(void) {
  Mimic_GPIO_Hardware_Init();
}

/**
 * @brief  System error handler. Traps execution.
 */
void APP_ErrorHandler(void) {
  while (1) {
  }
}

#ifdef USE_FULL_ASSERT
/**
 * @brief  Reports the name of the source file and the source line number
 * where the assert_param error has occurred.
 * @param  file: pointer to the source file name
 * @param  line: assert_param error line source number
 */
void assert_failed(uint8_t *file, uint32_t line) {
  while (1) {
  }
}
#endif /* USE_FULL_ASSERT */

/**
 * @brief Override standard library initialization hooks to prevent 
 * the inclusion of malloc, reent, and file system overloads.
 * This saves substantial FLASH and reclaims Heap RAM.
 */
void __libc_init_array(void) {
}

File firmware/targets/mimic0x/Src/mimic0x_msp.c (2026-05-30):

/**
 ******************************************************************************
 * @file    mimic0x_hal_msp.c
 * @author  TAKAGI Katsuyuki
 * @brief   MCU Support Package (MSP) Implementation for Base-Model Hardware, 
 * Handling Low-Level Peripheral Clock, GPIO, and NVIC Initializations.
 *-----------------------------------------------------------------------------
 * Copyright (C) 2026 TAKAGI Katsuyuki
 *
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
 * You should have received a copy of the GNU General Public License
 * along with this program.  If not, see <https://www.gnu.org/licenses/>.
 ******************************************************************************
 */

#include "mimic0x_msp.h"
#include "py32f0xx_hal.h"

/* ==================================================================== */
/* Hardware Revision Pin Definitions (mimic00)                          */
/* ==================================================================== */

#if defined(TARGET_MIMIC00)
  // I2C Peripheral Configuration Pins (PB6 / PB7)
  #define I2C_SCL_PORT      GPIOB
  #define I2C_SCL_PIN       GPIO_PIN_6
  #define I2C_SCL_AF        GPIO_AF1_I2C1 

  #define I2C_SDA_PORT      GPIOB
  #define I2C_SDA_PIN       GPIO_PIN_7
  #define I2C_SDA_AF        GPIO_AF1_I2C1

  // OPA1 Pins (Input Buffer)
  #define OPA1_INP_PIN      GPIO_PIN_9    // PA9
  #define OPA1_INN_PIN      GPIO_PIN_10   // PA10
  #define OPA1_OUT_PIN      GPIO_PIN_8    // PA8
  #define OPA1_PORT         GPIOA

  // OPA2 Pins (Output Driver / DAC2)
  #define OPA2_INP_PIN      GPIO_PIN_7    // PA7
  #define OPA2_INN_PIN      GPIO_PIN_6    // PA6
  #define OPA2_OUT_PIN      GPIO_PIN_5    // PA5
  #define OPA2_PORT         GPIOA

  // OPA3 Pins (Anti-Aliasing Filter)
  #define OPA3_INP_PIN      GPIO_PIN_13   // PB13
  #define OPA3_INN_PIN      GPIO_PIN_12   // PB12
  #define OPA3_OUT_PIN      GPIO_PIN_14   // PB14
  #define OPA3_PORT         GPIOB

  // ADC & DAC Pins
  #define ADC_IN9_PIN       GPIO_PIN_1    // PB1 (Reads AAF Out)
  #define ADC_IN9_PORT      GPIOB
  #define DAC1_OUT_PIN      GPIO_PIN_4    // PA4
  #define DAC_PORT          GPIOA
#elif defined(TARGET_MIMIC01)
  // I2C Peripheral Configuration Pins (PB6 / PB7)
  #define I2C_SCL_PORT      GPIOB
  #define I2C_SCL_PIN       GPIO_PIN_6
  #define I2C_SCL_AF        GPIO_AF1_I2C1 

  #define I2C_SDA_PORT      GPIOB
  #define I2C_SDA_PIN       GPIO_PIN_7
  #define I2C_SDA_AF        GPIO_AF1_I2C1

  // OPA1 Pins (Input Buffer)
  #define OPA1_INP_PIN      GPIO_PIN_9    // PA9
  #define OPA1_INN_PIN      GPIO_PIN_10   // PA10
  #define OPA1_OUT_PIN      GPIO_PIN_8    // PA8
  #define OPA1_PORT         GPIOA

  // OPA2 Pins (Output Driver / DAC2)
  #define OPA2_INP_PIN      GPIO_PIN_7    // PA7
  #define OPA2_INN_PIN      GPIO_PIN_6    // PA6
  #define OPA2_OUT_PIN      GPIO_PIN_5    // PA5
  #define OPA2_PORT         GPIOA

  // OPA3 Pins (Anti-Aliasing Filter)
  #define OPA3_INP_PIN      GPIO_PIN_13   // PB13
  #define OPA3_INN_PIN      GPIO_PIN_12   // PB12
  #define OPA3_OUT_PIN      GPIO_PIN_14   // PB14
  #define OPA3_PORT         GPIOB

  // ADC & DAC Pins
  #define ADC_IN9_PIN       GPIO_PIN_1    // PB1 (Reads AAF Out)
  #define ADC_IN9_PORT      GPIOB
  #define DAC1_OUT_PIN      GPIO_PIN_4    // PA4
  #define DAC_PORT          GPIOA

  // LED
  #define READY_LED_PORT    GPIOF
  #define READY_LED_PIN     GPIO_PIN_6
  // Test pad
  #define TEST_PAD_PORT     GPIOA
  #define TEST_PAD_PIN      GPIO_PIN_2
#else
  #error "Hardware revision macro is not defined! Please define HW_REV_MIMIC00 in your build configuration."
#endif

/* ==================================================================== */
/* Interrupt Priority Definitions                                       */
/* ==================================================================== */
#define I2C_IRQ_PRIORITY    1
#define ADC_IRQ_PRIORITY    0

/* ==================================================================== */
/* System Initialization                                                */
/* ==================================================================== */
void HAL_MspInit(void)
{
  __HAL_RCC_SYSCFG_CLK_ENABLE();
  __HAL_RCC_PWR_CLK_ENABLE();
}

/* ==================================================================== */
/* Analog Initialization (OPA, ADC, DAC)                                */
/* ==================================================================== */
void HAL_OPA_MspInit(OPA_HandleTypeDef *hopa)
{
  GPIO_InitTypeDef GPIO_InitStruct = {0};

  /* Enable GPIO Clocks */
  __HAL_RCC_GPIOA_CLK_ENABLE();
  __HAL_RCC_GPIOB_CLK_ENABLE();

  /* Enable OPA peripheral clock */
  __HAL_RCC_OPA_CLK_ENABLE();

  /* All Analog pins must be set to GPIO_MODE_ANALOG */
  GPIO_InitStruct.Mode  = GPIO_MODE_ANALOG;
  GPIO_InitStruct.Pull  = GPIO_NOPULL;

  switch(hopa->Init.Part) {
    case OPA1:
      GPIO_InitStruct.Pin = OPA1_INP_PIN | OPA1_INN_PIN | OPA1_OUT_PIN;
      HAL_GPIO_Init(OPA1_PORT, &GPIO_InitStruct);
      break;
    case OPA2:
      GPIO_InitStruct.Pin = OPA2_INP_PIN | OPA2_INN_PIN | OPA2_OUT_PIN;
      HAL_GPIO_Init(OPA2_PORT, &GPIO_InitStruct);
      break;
    case OPA3:
      GPIO_InitStruct.Pin = OPA3_INP_PIN | OPA3_INN_PIN | OPA3_OUT_PIN;
      HAL_GPIO_Init(OPA3_PORT, &GPIO_InitStruct);
      break;
    default:
      break;
  }
}

void HAL_ADC_MspInit(ADC_HandleTypeDef *hadc)
{
  GPIO_InitTypeDef GPIO_InitStruct = {0};

  if(hadc->Instance == ADC1)
  {
    __HAL_RCC_ADC_CONFIG(RCC_ADCCLKSOURCE_PCLK_DIV4);

    __HAL_RCC_GPIOB_CLK_ENABLE();
    __HAL_RCC_ADC_CLK_ENABLE();

    GPIO_InitStruct.Pin  = ADC_IN9_PIN;
    GPIO_InitStruct.Mode = GPIO_MODE_ANALOG;
    GPIO_InitStruct.Pull = GPIO_NOPULL;
    HAL_GPIO_Init(ADC_IN9_PORT, &GPIO_InitStruct);

    HAL_NVIC_SetPriority(ADC_COMP_IRQn, ADC_IRQ_PRIORITY, 0); 
    HAL_NVIC_EnableIRQ(ADC_COMP_IRQn);
  }
}

void HAL_DAC_MspInit(DAC_HandleTypeDef *hdac)
{
  GPIO_InitTypeDef GPIO_InitStruct = {0};

  if(hdac->Instance == DAC1)
  {
    __HAL_RCC_GPIOA_CLK_ENABLE();
    __HAL_RCC_DAC1_CLK_ENABLE();

    // Initialize DAC1_OUT (PA4) 
    GPIO_InitStruct.Pin  = DAC1_OUT_PIN;
    GPIO_InitStruct.Mode = GPIO_MODE_ANALOG;
    GPIO_InitStruct.Pull = GPIO_NOPULL;
    HAL_GPIO_Init(DAC_PORT, &GPIO_InitStruct);
  }
}

/* ==================================================================== */
/* Timer Initialization (TIM3)                                          */
/* ==================================================================== */
void HAL_TIM_Base_MspInit(TIM_HandleTypeDef *htim_base)
{
  if(htim_base->Instance == TIM3)
  {
    /* Enable TIM3 peripheral clock */
    __HAL_RCC_TIM3_CLK_ENABLE();
  }
}
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

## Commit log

2026-05-22 Add hybrid open-source licenses (CERN-OHL-S, GPLv3, MIT)
    [mimic00.kicad_pcb, mimic00.kicad_sch, mimic01.kicad_pcb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]
2026-05-22 Update silk and component values
    [mimic01.kicad_pcb, mimic01.kicad_sch]
2026-05-29 Add MIMIC_REG_CMD_PORT. Fix the flash protcol, and the main loop.
    [main.c, mimic_device.c, mimic_dsp.c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]
2026-05-30 Add: a script to generate Arduino libraries Delete: unnecessary .gitignore
2026-05-30 Split arduino library (software) into analog-mimic-arduino
2026-05-30 Add: Ready-LED and test pad for Mimic01 only
2026-06-02 Add board and pinout images
    Updated images in README and added new board image.
2026-06-02 Add static_assert to prevent phase-shift jitter from odd sampling periods due to 2-phase AHB bus misalignment
2026-10-19 Code cleanup: Consolidated hardware-related operations into `mimic0x_msp`. Only time-critical processes remain in `dsp`. Modified `main.c` to contain only a WFI (Wait For Interrupt) loop.
2026-10-20 Stop tracking KiCad local project settings
2026-10-20 fix for KiCad
2026-10-20 change input bias voltage
2026-10-25 add I2C address function
2026-10-27 changed: input bias voltage, VDD/2. pullup resistor value, 10k. silk texts. add OSHW logo
2026-10-27 update KiCad version

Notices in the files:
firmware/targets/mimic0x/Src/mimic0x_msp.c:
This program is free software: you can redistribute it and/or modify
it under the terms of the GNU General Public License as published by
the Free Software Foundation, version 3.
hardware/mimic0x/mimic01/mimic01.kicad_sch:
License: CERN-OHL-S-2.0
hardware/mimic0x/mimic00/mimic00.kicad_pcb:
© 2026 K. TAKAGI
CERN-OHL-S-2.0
